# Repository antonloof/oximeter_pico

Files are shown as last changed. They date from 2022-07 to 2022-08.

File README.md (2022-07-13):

# Oximeter for the Raspberry pi PICO

ETA-dagen projekt 2022. Mäter din puls och visar den på ett par 7segmentsdisplayer

## 7 Segment
Använder [PIO](https://www.raspberrypi.com/news/what-is-pio/) för att [multiplexa](https://embedded-lab.com/blog/lab-11-multiplexing-seven-segment-led-displays/) displayerna.
PIO matas kontinuerligt av DMA med minimal interaktion från processorn. 

## Hur mäter man puls
Kort svar. Du mäter hur blodet rör sig i dina ådror. Syrerikt och syrfattigt blod absorberar och reflekterar olika mycket ljus.
Vi mäter hur mycket ljus som absorberar av bloded och får reda på om det finns mycket eller lite syre i blodet. 
Ett hjärtslag består av att först trycka ut syrerikt blod och sedan suga tillbaka syrefattigt blod. Det innenbär att ett slag innebär en ökning och sedan en miskning av mängden syre i blodet. Koden filtrerar först "hur mycket syre finns det i blodet"-signalen för att minska bruset. Efter det mäter den tiden mellan maximum av signalen. Detta är periodtiden på dina hjärtslag 1/period ger frekvens.

## Filter?
Vi använder ett 2a ordningens digitalt butterwurth filter. Ni kommer lära er mer om dessa snart (tm) i tex Kretsanalys. 

## Hur hittar vi maximum?
Vi letar efter toppar i signalen som omringas av en dal före och en dal efter. Dessa dalar måste vara "djupa" i förhållande till signalen för att vi ska räkna toppen som en topp. 

## Hur kommer man igång?
https://github.com/ndabas/pico-setup-windows
Ladda ner och kör, detta installerar vscode och toolchain för att bygga projektet och programmera din PICO.

## Vilken sektion?
E!

## Vilken färg?
GUL!

## Vilket skyddshelgon?
KALLE ANKA!

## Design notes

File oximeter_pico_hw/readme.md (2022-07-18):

# HW sidan av projektet

## Förklaring av schema

- U1 är våran mikrokontrollermodul, som sköter allting.
- U2 är själva sensor som mäter puls och blodsyrenivåer genom att lysa lite LEDs, som styrs med transistorer Q5-Q7, och mäta hur stark är ljuset efter den går igenom cellerna i din finger. Den innehåller en fotodiod, som släpper en viss mängd ström beroende på ljusstyrkan- tillsammans med R9 bildar den en sorts variabel spänningsdelare, och resulterande analogt värde läses av Pico:n.
- U3 och U4 är 7-segmentsdisplayer, och båda innehåller LED:s för 2 siffror. Segmenter tänds genom själva pinnarna av Pico:n, och transistorer Q1-Q4 väljer vilken segment ska lysa. Resistorer R1-R8 begränsar ström som segmenter ska ta.

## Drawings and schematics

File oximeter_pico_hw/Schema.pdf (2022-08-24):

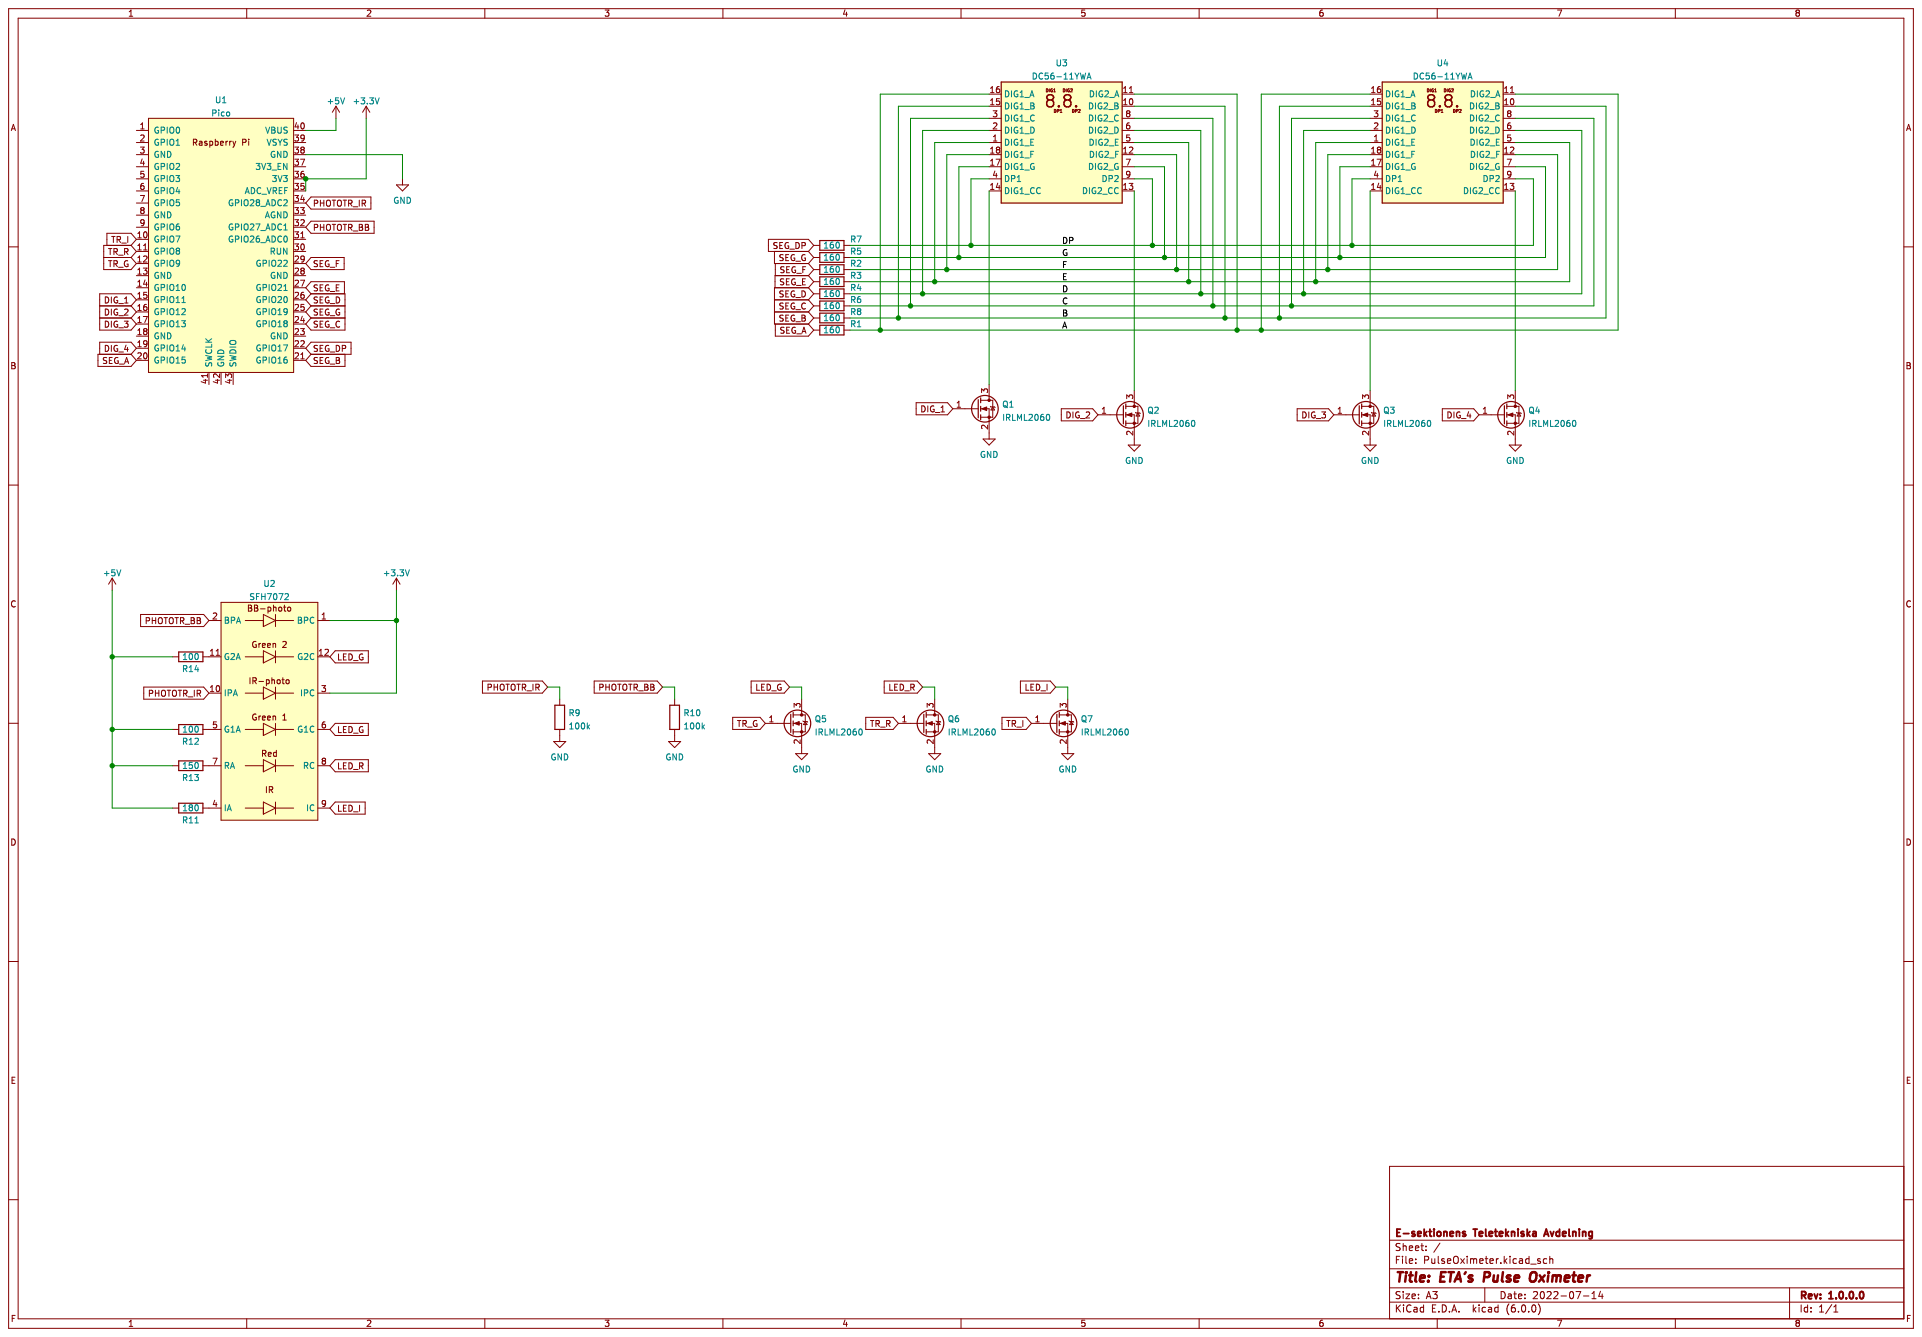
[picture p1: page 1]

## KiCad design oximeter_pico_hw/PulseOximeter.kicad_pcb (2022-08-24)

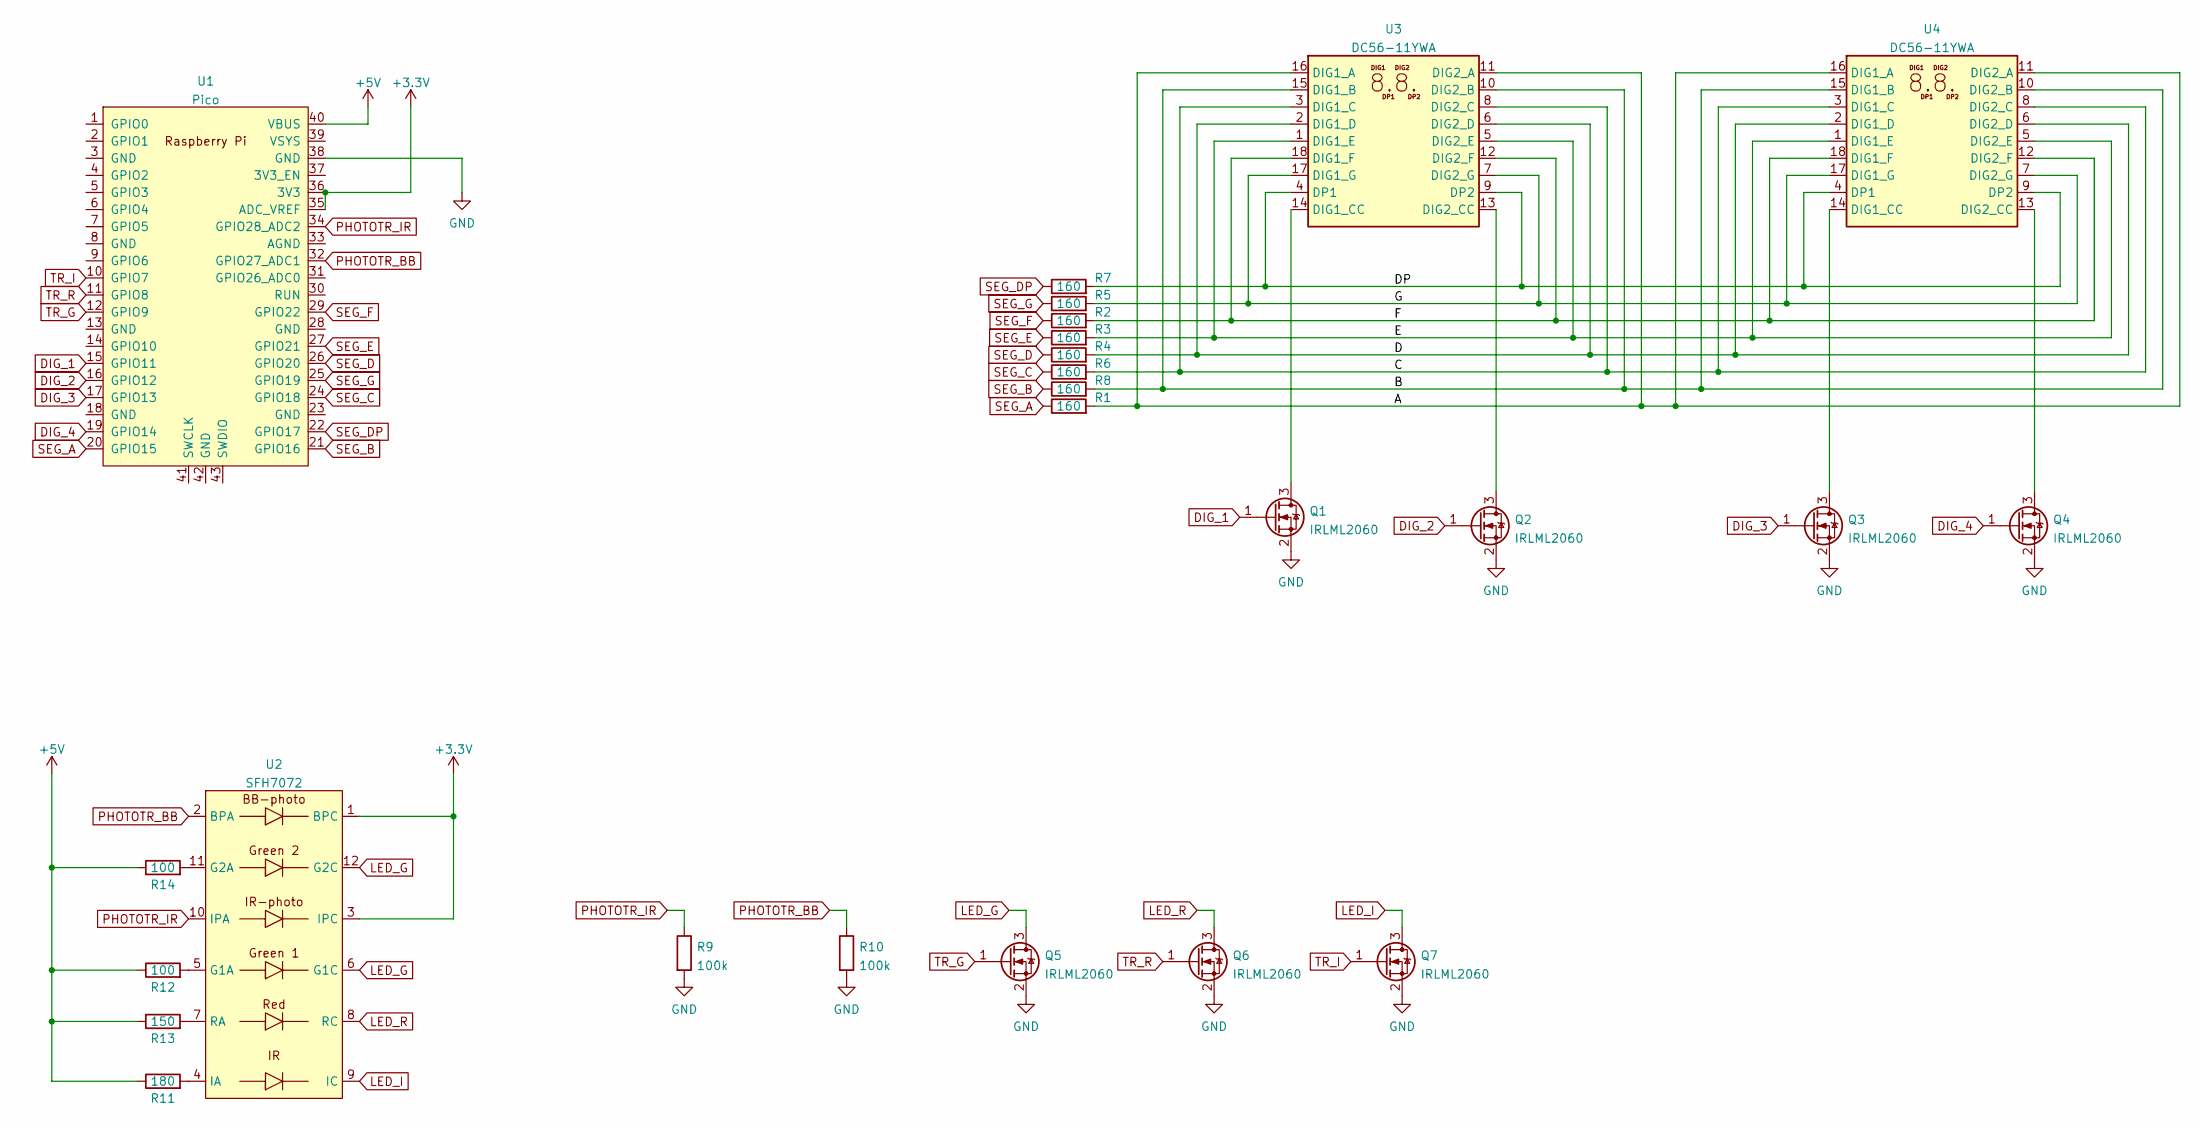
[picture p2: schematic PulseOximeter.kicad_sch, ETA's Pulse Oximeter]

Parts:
Q1, Q2, Q3, Q4, Q5, Q6, Q7: IRLML2060; SOT-23
R1, R2, R3, R4, R5, R6, R7, R8: 160; R_Axial_DIN0207_L6.3mm_D2.5mm_P15.24mm_Horizontal
R9, R10: 100k; R_Axial_DIN0207_L6.3mm_D2.5mm_P15.24mm_Horizontal
R11: 180; R_Axial_DIN0207_L6.3mm_D2.5mm_P15.24mm_Horizontal
R12, R14: 100; R_Axial_DIN0207_L6.3mm_D2.5mm_P15.24mm_Horizontal
R13: 150; R_Axial_DIN0207_L6.3mm_D2.5mm_P15.24mm_Horizontal
U1: Pico; RPi_Pico_SMD_TH
U2: SFH7072
U3, U4: DC56-11YWA; DA56-11SYKWA

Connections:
+3V3: U1.35 (ADC_VREF), U1.36 (3V3), U2.1 (BPC), U2.3 (IPC)
+5V: R11.1, R12.1, R13.1, R14.1, U1.40 (VBUS)
/A: R1.2, U3.11 (DIG2_A), U3.16 (DIG1_A), U4.11 (DIG2_A), U4.16 (DIG1_A)
/B: R8.2, U3.10 (DIG2_B), U3.15 (DIG1_B), U4.10 (DIG2_B), U4.15 (DIG1_B)
/C: R6.2, U3.3 (DIG1_C), U3.8 (DIG2_C), U4.3 (DIG1_C), U4.8 (DIG2_C)
/D: R4.2, U3.2 (DIG1_D), U3.6 (DIG2_D), U4.2 (DIG1_D), U4.6 (DIG2_D)
/DP: R7.2, U3.4 (DP1), U3.9 (DP2), U4.4 (DP1), U4.9 (DP2)
/E: R3.2, U3.1 (DIG1_E), U3.5 (DIG2_E), U4.1 (DIG1_E), U4.5 (DIG2_E)
/F: R2.2, U3.12 (DIG2_F), U3.18 (DIG1_F), U4.12 (DIG2_F), U4.18 (DIG1_F)
/G: R5.2, U3.7 (DIG2_G), U3.17 (DIG1_G), U4.7 (DIG2_G), U4.17 (DIG1_G)
DIG_1: Q1.1 (G), U1.15 (GPIO11)
DIG_2: Q2.1 (G), U1.16 (GPIO12)
DIG_3: Q3.1 (G), U1.17 (GPIO13)
DIG_4: Q4.1 (G), U1.19 (GPIO14)
GND: Q1.2 (S), Q2.2 (S), Q3.2 (S), Q4.2 (S), Q5.2 (S), Q6.2 (S), Q7.2 (S), R9.2, R10.2, U1.38 (GND)
LED_G: Q5.3 (D), U2.6 (G1C), U2.12 (G2C)
LED_I: Q7.3 (D), U2.9 (IC)
LED_R: Q6.3 (D), U2.8 (RC)
unnamed: Q1.3 (D), U3.14 (DIG1_CC)
unnamed: Q2.3 (D), U3.13 (DIG2_CC)
unnamed: Q3.3 (D), U4.14 (DIG1_CC)
unnamed: Q4.3 (D), U4.13 (DIG2_CC)
unnamed: R11.2, U2.4 (IA)
unnamed: R12.2, U2.5 (G1A)
unnamed: R13.2, U2.7 (RA)
unnamed: R14.2, U2.11 (G2A)
PHOTOTR_BB: R10.1, U1.32 (GPIO27_ADC1), U2.2 (BPA)
PHOTOTR_IR: R9.1, U1.34 (GPIO28_ADC2), U2.10 (IPA)
SEG_A: R1.1, U1.20 (GPIO15)
SEG_B: R8.1, U1.21 (GPIO16)
SEG_C: R6.1, U1.24 (GPIO18)
SEG_D: R4.1, U1.26 (GPIO20)
SEG_DP: R7.1, U1.22 (GPIO17)
SEG_E: R3.1, U1.27 (GPIO21)
SEG_F: R2.1, U1.29 (GPIO22)
SEG_G: R5.1, U1.25 (GPIO19)
TR_G: Q5.1 (G), U1.12 (GPIO9)
TR_I: Q7.1 (G), U1.10 (GPIO7)
TR_R: Q6.1 (G), U1.11 (GPIO8)

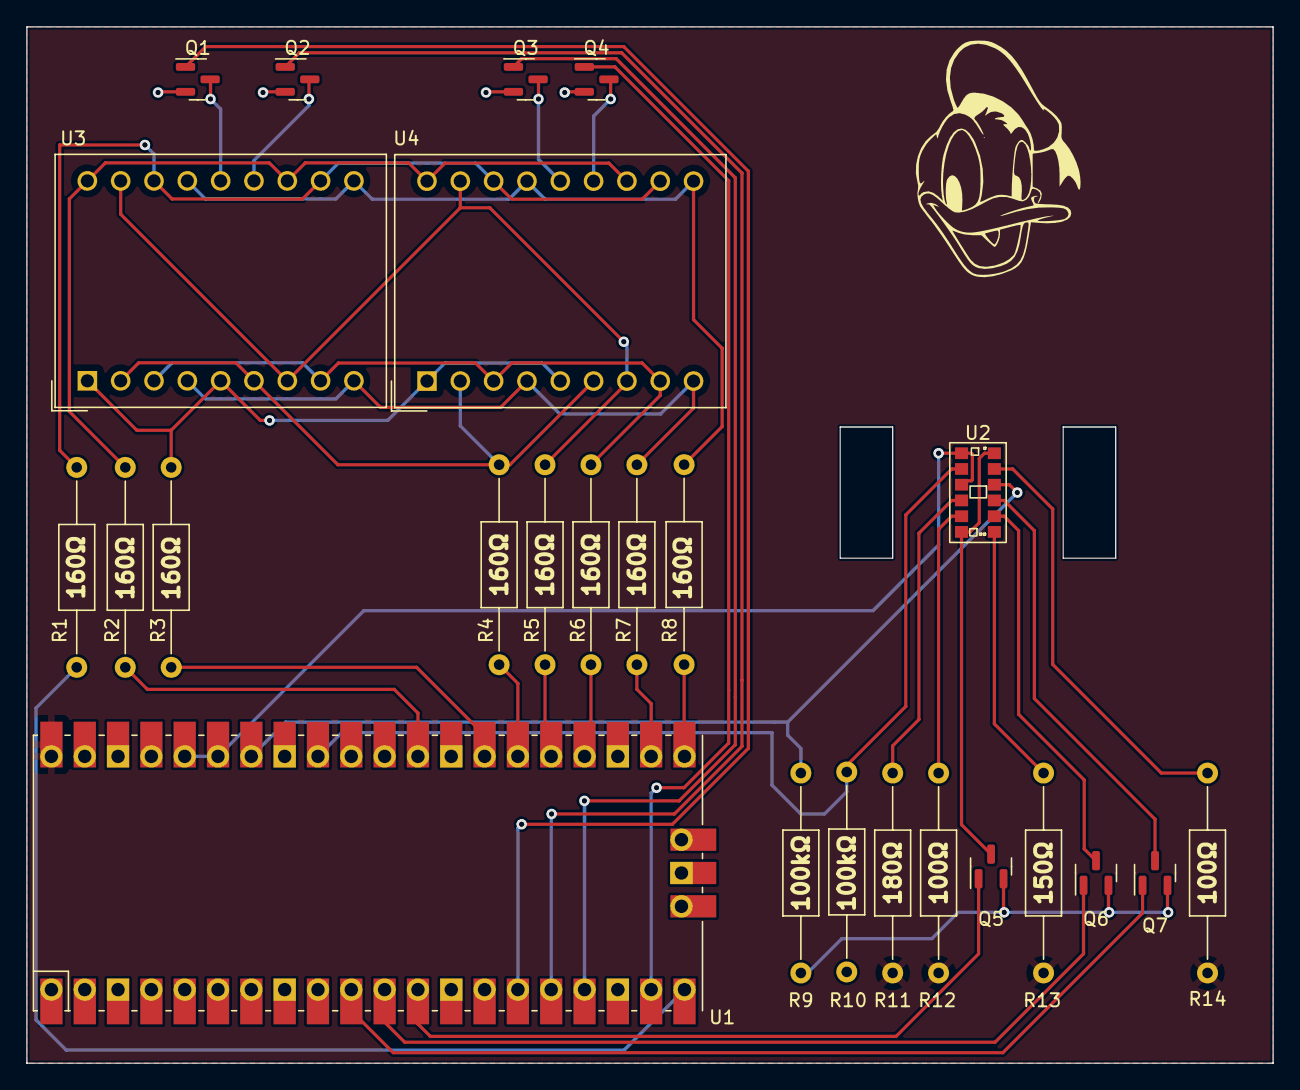
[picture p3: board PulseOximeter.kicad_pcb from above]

Board: 2 copper layers, 95.0 x 79.0 mm, 25 parts (0 on the bottom side), 39 nets.

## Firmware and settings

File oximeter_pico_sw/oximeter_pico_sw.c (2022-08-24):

#include <stdio.h>
#include "pico/stdlib.h"
#include "hardware/pio.h"
#include "7seg.h"
#include "hardware/adc.h"
#include "digital_filter.h"
#include "heartbeat_detector.h"

#define SAMPLE_RATE_HZ 1000.0f
#define HZ_TO_BPM 60.0f

#define PHOTODIODE_IR_PIN 28
#define PHOTODIODE_BB_PIN 27

#define DISPLAY_BASE_PIN 11

#define RED_LED_PIN 8
#define GREEN_LED_PIN 9
#define IR_LED_PIN 7

void seven_seg_irq();

seg7_state seven_seg = {
    .dig_count = 4,
    .seg_count = 8,
    .pin_order = {3, 2, 1, 0, 8, 11, 10, 9, 7, 5, 4, 6},
    .pio = pio0,
    .start_pin = DISPLAY_BASE_PIN,
    .irq = &seven_seg_irq};

void seven_seg_irq()
{
    seg7_dma_irq_handler(&seven_seg);
}

bool repeating_timer_callback(struct repeating_timer *t);
void init_sampling(uint pin);
void process_sample(float sample);
volatile bool should_sample;

// second order BW bandpass from 0.1 to 3 hz at a sample rate of 1kS/s
float fb[3] = {0.007792936291952f, 0.0f, -0.007792936291952f};
float fa[2] = {-1.984355370350682f, 0.984414127416097f};
float fx[3], fz[2];

filter input_filter = {
    .a = fa,
    .b = fb,
    .alen = 2,
    .blen = 3,
    .x = fx,
    .z = fz};

repeating_timer_t timer;
void new_heartrate_callback(uint32_t *periods);
heartbeat_detector hb = {
    .peak_to_peak_filter = 0.9995,
    .callback = new_heartrate_callback};

int main()
{
    stdio_init_all();
    init_sampling(PHOTODIODE_BB_PIN);
    seg7_init(&seven_seg);
    // enable the ir led for now, we need to use all leds to measure oxygen content of the blood
    // pulse oximetry is left as an exercise to the reader
    gpio_set_drive_strength(GREEN_LED_PIN, GPIO_DRIVE_STRENGTH_12MA);
    gpio_init(GREEN_LED_PIN);
    gpio_set_dir(GREEN_LED_PIN, true);
    gpio_put(GREEN_LED_PIN, 1);

    add_repeating_timer_ms(-1, repeating_timer_callback, NULL, &timer);

    while (1)
    {
        if (should_sample)
        {
            process_sample((float)adc_read());
        }
    }

    return 0;
}

void init_sampling(uint pin)
{
    should_sample = false;
    adc_init();
    adc_gpio_init(pin);
    adc_select_input(pin - 26);
    heartbeat_detector_init(&hb);
}

bool repeating_timer_callback(struct repeating_timer *t)
{
    should_sample = true;
    return true; // continue repeating timer :D
}

void process_sample(float sample)
{
    float filtered = filter_process((float)sample, &input_filter);
    printf("%f %f\n", filtered, sample);
    heartbeat_detector_sample(filtered, &hb);
    should_sample = false;
}

void new_heartrate_callback(uint32_t *periods)
{

    seg7_display((uint)round(SAMPLE_RATE_HZ / (float)periods[0] * HZ_TO_BPM), false, &seven_seg);
}

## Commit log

2022-07-13 Add HW project files
    [PulseOximeter-B_Cu.gbr, PulseOximeter-B_Mask.gbr, PulseOximeter-B_Paste.gbr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]
2022-07-22 update 7seg driver
2022-07-22 tweak sw still not working
    [oximeter_pico_sw.c]
2022-08-24 Update HW to revision 2
    [PulseOximeter-B_Cu.gbr, PulseOximeter-B_Mask.gbr, PulseOximeter-B_Paste.gbr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]
